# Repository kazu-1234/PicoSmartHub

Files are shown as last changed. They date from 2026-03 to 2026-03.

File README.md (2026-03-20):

# PicoSmartHub

PicoSmartHubは、Raspberry Pi Pico W 2（およびPico W）をコアとして開発された、多機能かつ統合的なスマートホームハブ兼環境測定ステーションです。
単なるセンサーノードにとどまらず、外部クラウドサービス（SwitchBot, LINE, Google Apps Script）との連携、赤外線通信、およびローカルネットワーク内での子機連携を安定して処理できるように設計されています。

## 外観・ハードウェア構成

メイン画面
メイン画面

### 電源供給について
本システムは、設置環境に応じて「USB給電」と「乾電池」の2種類の電源方式で動作するように設計されています。これにより、コンセントがない場所でもスタンドアローンで稼働させることが可能です。
**USBケーブルによる給電と、乾電池による給電を絶対に同時に行わないでください。**

## コア機能と技術詳細

本システムは、日常生活の利便性向上と環境監視を目的として、以下の主要な機能を備えています。

### 1. 高度な環境センシングと異常検知
本体および外部センサーを用いて、生活環境を常に監視します。
- **高精度な温湿度測定**: 本体内蔵のDHT20で室内の温湿度を常時測定します。また、屋外や別室を測定するための外部センサー（DHT22）は、本体のイヤホンジャック端子を利用して接続する設計となっており、用途に合わせて容易に着脱が可能です。すべての測定結果はLCDに一覧表示されます。
- **雷雲接近のリアルタイム検知**: AS3935雷センサーモジュールを搭載。ハードウェア割り込み（IRQ）を用いてバックグラウンドで雷の発生を監視し、検知時には「雷までの推定距離」を即座に算出して画面に警告表示します。同時にRGB LEDを黄色点滅させ、視覚的にも危険を知らせます。

### 2. 子機（PicoSmartHub_Sub）とのローカルネットワーク連携
同一Wi-Fiネットワーク内に配置した別プロジェクトの子機（[PicoSmartHub_Sub](https://github.com/kazu-1234/PicoSmartHub_Sub)）とTCP/IP経由で直接通信を行い、リアルタイムな状態共有を実現しています。
- **お風呂の湯張り監視システム**: 子機に搭載された超音波距離センサーが浴槽の水位を監視します。水位が事前に設定した閾値に達すると、子機から親機に対してプッシュ通知（HTTPリクエスト等）が送信されます。
- **親機側のアラート処理**: 通知を受け取った親機は、現在実行中の画面表示を強制的にオーバーライドして「お風呂が沸いたこと」を画面に大きく表示し、同時にRGB LEDを白色の無限点滅モードに切り替えてユーザーに確実に知らせます。

### 3. 統合的な家電制御（SwitchBot API & ローカル赤外線）
赤外線方式の家電を本機から一括制御します。
- **SwitchBotクラウド連携**: `config.h` に登録したSwitchBotのAPIトークンおよびデバイスIDを利用し、ネットワーク経由で照明、テレビ、エアコンなどを本体の物理ボタン・メニューから直接操作可能です。APIのレスポンス処理もマイコン内で完結しています。
- **赤外線（IR）の学習と送信**: 赤外線受信モジュールを用いて既存のリモコンの信号を読み取り、マイコン内に記録する学習モードを実装。記録した信号は赤外線送信LEDから出力でき、ローカル環境のみで完結する遅延のない家電操作を実現しています。

### 4. 双方向の外部サービス連携（GAS & LINE API）
マイコン単体では難しいデータの蓄積や遠隔からの操作を、Google Apps Script (GAS) とLINE Messaging APIを組み合わせることで解決しています。
- **環境データのクラウドロギング**: 定期的に温湿度データや雷の検知ログをGASへ送信し、Googleスプレッドシートに自動追記します。これにより、過去の環境データのグラフ化や分析が可能です。
LINEからの操作

- **LINEへの自動警告と遠隔操作**: 雷接近時にLINEへ自動でメッセージをプッシュ送信します。また、外出先からLINEのBot宛てに特定のメッセージ（例：「PC起動」）を送信すると、GASを経由して親機がそのリクエストを検知し、後述のWoL機能などを実行する双方向通信を構築しています。

### 5. Wake on LAN (WoL) によるPC電源管理
あらかじめ設定ファイルに登録されたデスクトップPCやホームサーバーのMACアドレスに対し、マジックパケットを生成・ブロードキャスト送信します。これにより、物理的なスイッチを押すことなく、本機からのメニュー操作やLINE経由でのリモート起動が可能です。

LINEからの操作

### 6. デュアルコアを活用したシステムアーキテクチャ
Raspberry Pi Pico W 2 のRP2350（またはRP2040）のデュアルコアを最大限に活用し、処理のブロッキングを防いでいます。
- **Core 0**: センサーの読み取り、LCDの描画、ボタン入力の判定、赤外線の送受信など、タイミングがシビアなハードウェア制御とUI処理を担当。
- **Core 1**: Wi-Fiの接続維持、HTTPリクエストの送信（SwitchBot/GAS等）、WoLパケットの生成、子機からの通信待受など、時間のかかる重いネットワーク処理をバックグラウンドで担当。

## 回路構成・ピンアサイン詳細

Raspberry Pi Pico W 2 (Pico W 互換) との結線は以下の通りです。

- **LCDディスプレイ (20x4文字表示 / LiquidCrystal互換)**
  - RS: GP2
  - E: GP3
  - D4: GP4, D5: GP5, D6: GP6, D7: GP7
  - バックライト (PWM調光用): GP14
- **RGB LED (ステータス・アラート用)**
  - Red: GP28, Green: GP27, Blue: GP26
- **ユーザーインターフェース**
  - 操作ボタン入力: GP15 (内部プルアップ有効)
- **I2Cバス (各種センサー通信用)**
  - SDA: GP0
  - SCL: GP1
  - 接続デバイス: DHT20 (室内温湿度), AS3935 (雷センサー)
- **センサー個別ピン**
  - AS3935 割り込み (IRQ): GP16
  - DHT22 (屋外用温湿度) データ: GP17 （※イヤホンジャック経由で着脱可能）
- **赤外線 (IR) モジュール**
  - IR受信 (OUT): GP18
  - IR送信LED (IN): GP19

## 導入・セットアップ手順

1. **開発環境の準備**
   Arduino IDEを使用します。ボードマネージャで Raspberry Pi Pico / RP2040 (earlephilhower版) をインストールしてください。
2. **必須ライブラリのインストール**
   ライブラリマネージャから以下のライブラリをインストールします。
   - `LiquidCrystal`
   - `DFRobot_DHT20`
   - `DHT sensor library` (Adafruit)
   - `SparkFun AS3935 Lightning Sensor`
   - `ArduinoJson`
   - `IRremote`
3. **`config.h` の設定**
   プロジェクト内の `config.h` を環境に合わせて編集してください。
   - Wi-Fi接続情報（複数APのフォールバック対応）
   - 固定IP・ゲートウェイ設定
   - 子機（PicoSmartHub_Sub）のIPアドレス
   - WoL対象機器のMACアドレス
   - 各種APIキー（SwitchBot, LINE, GASデプロイURL）
4. **コンパイルと書き込み**
   ボードを「Raspberry Pi Pico W」等に設定し、書き込みを行います。初回起動時はWi-Fi接続とNTPサーバーによる時刻同期が行われ、完了後にメインシステムが立ち上がります。

## ライセンス
本ソフトウェアは MIT License のもとで公開されています。詳細は `LICENSE` ファイルをご確認ください。

## 免責事項
本システムは個人開発によるプロジェクトです。本ソフトウェアおよびハードウェア設計の使用によって生じたいかなる損害（データの損失、家電の誤作動、感電等の事故）について、開発者は一切の責任を負いません。特に、子機を用いた水回りでの運用、WoL等による外部からのシステム起動、およびUSBと乾電池の電源取り扱いに関しては、十分な安全確認と自己責任の上で運用してください。

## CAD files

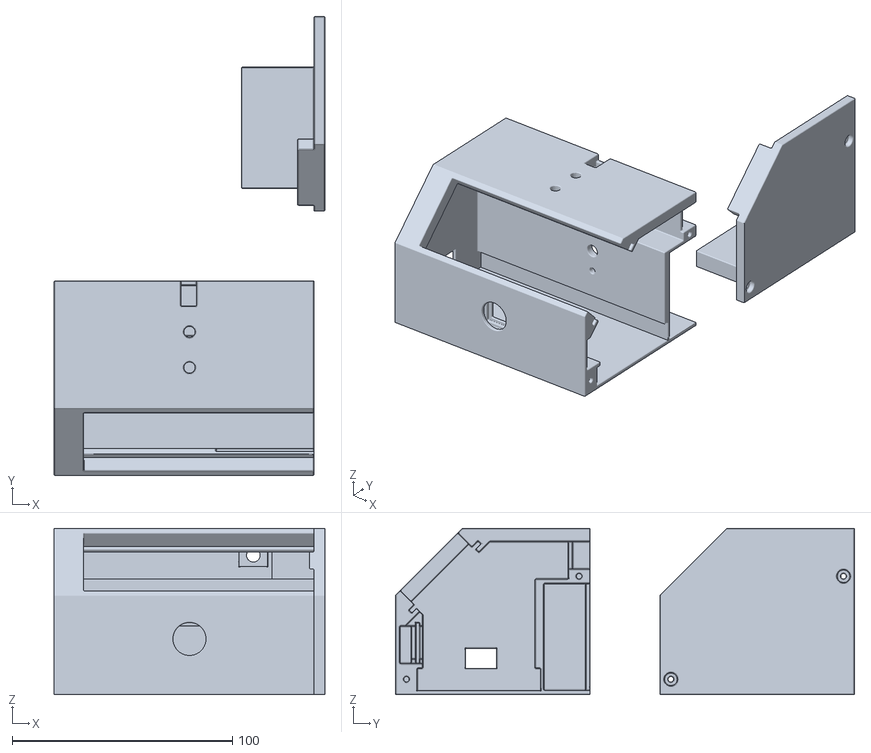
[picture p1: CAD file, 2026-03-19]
3D_data/PicoSmartHub.stl
123.0 x 208.4 x 75.5

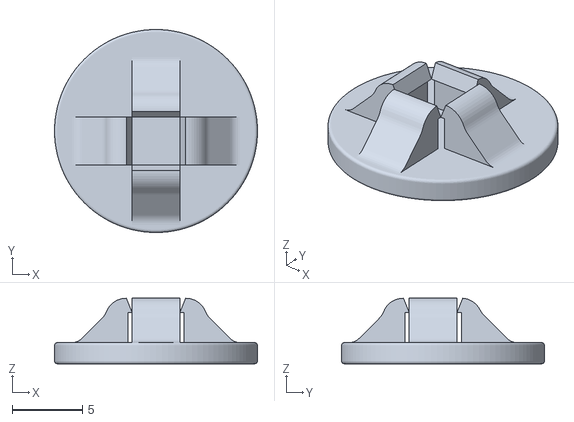
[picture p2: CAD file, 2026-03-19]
3D_data/PicoSmartHub_button.stl
14.4 x 14.4 x 4.65

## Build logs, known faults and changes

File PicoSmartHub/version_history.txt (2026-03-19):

Thunder Sensor - バージョン履歴
================================

v19.2.0
- 旧バージョン（安定版）

v19.3.0 (2026-03-06)
- 動作安定化修正（機能変更なし）
- HTTPリクエスト読み取りのbusy-waitにdelay(1)を追加してCPU解放・Watchdog保護
- handleLEDBlink()のmutex取得前にledBlinkActiveフラグの事前チェックを追加（mutex競合軽減）
- distance_start / distance_stop 送信後のdelay(100)→delay(10)に短縮
- requestSendBathClear処理のdelay(50)→delay(10)に短縮
- bath_clear処理のフォーマットバグ修正（{ の直後にコードが続いていた）
- SwitchBotコマンドキューのローカルバッファをゼロ初期化してNULL終端を保証

v19.3.1 (2026-03-06)
- 5-7秒間隔のフリーズ修正
- handleWolPollingのポーリング間隔を5秒→30秒に延長（Core1のwifi_mutex長時間保持を軽減）
- handleWolPollingのHTTPSリトライを除去し1回のみに変更、タイムアウトを5秒→3秒に短縮
- handleWolPolling内のdelay(200)→delay(100)に短縮
- logDataToGoogleSheetのタイムアウトを5秒→3秒に短縮
- handleActionFlags内のWiFiClient接続にsetTimeout(1000)を追加（接続タイムアウト1秒制限）
- handleActionFlags内のdelay()をflush()+stop()に置換（ノンブロッキング化）

v19.4.0 (2026-03-06)
- 起動直後の即フリーズおよびWatchdog再起動ループの原因（Core0 setup完了直前の String 型への代入時のヒープ競合）を修正（data_mutexによる保護を追加）
- 未確定なタイムアウト短縮やポーリング延長設定を破棄し、完全に安定動作していた旧バージョン（v19.2.0以前）の通信間隔・タイムアウト等に完全復元
  - GAS / WoLポーリング間隔を30秒→5秒に復元
  - GAS / WoL通信タイムアウトを3秒→5秒に復元
  - WoLポーリング通信のリトライ（2回）とdelay待機を復元

v19.6.0 (2026-03-07)
- 起動時フリーズおよび秒更新の定期停止の根本原因を修正（WiFiミューテックス長期保持・ブロッキングNTP）
- handleConnection(): NTP同期をステートマシン化し完全非同期化
  - 旧: for(i<60){ delay(200); } = 12秒間Core1完全ブロック → 起動直後にアニメーションが動かない原因
  - 新: NTP.begin()後すぐリターン、ntpWaiting/ntpWaitStartフラグで次ループにて結果確認
  - 12秒タイムアウトもノンブロッキングでmillis()比較により管理
- handleServerClient(): server.accept()前の不要なwifi_mutexロックを除去
  - server.accept()はブロッキングでなくポーリング操作のため排他不要
- handleWolPolling(): wifi_mutexを関数全体ではなくHTTPリクエストごとに取得・解放
  - 旧: 関数先頭でmutex取得→全HTTPリクエスト完了まで保持（最大25秒以上）→ 秒更新が定期停止する原因
  - 新: シグナル確認・コマンド取得・ACK送信の各リクエストを個別にmutex取得・解放
- handleWolPolling(): リトライ待機をdelay(500)→delay(100)に短縮

v19.5.0 (2026-03-06)
- 3〜30秒間隔の不規則フリーズ（Watchdog誤発火）の根本原因を修正
- petWatchdog()ヘルパーを追加し、loop()内の複数箇所から呼び出し
  - Display::update()のmutex待ち前後、handlePeriodicTasks()後、delay(10)直前も呼び出し
  - DHT22読み取り前後でも呼び出し（最大2.5秒かかる場合に対応）
- FREEZE_TIMEOUT_MSを10秒→15秒に延長（WiFi/HTTPS処理中の誤Watchdog防止）
- Display::update()のmutex_enter_blockingをtry_enterスピンに変更（デッドロック根絶）
  - Core1がwifi_mutex＋data_mutexを長時間保持中でもCore0がタイムアウトしない
  - 2秒以内にmutex取得できない場合はそのフレームのLCD更新をスキップ（次フレームで回復）
- checkInactivity()をtry_enter（取れなければスキップ）に変更
- handleLEDBlink()をtry_enter（取れなければその呼び出しをスキップ）に変更
- handleButton()の短押し・長押し処理をtry_enterスピンに変更
- loop()末尾の二重バックライトチェック（mutex_enter_blocking）を削除（handlePeriodicTasksで管理済み）
- Core1のloop1()でCore0起動完了前はWatchdog監視を開始しないよう変更（起動時誤トリガー防止）
- WiFi連続失敗時のdelay(5000)を1秒×5回ループに分割（Core1ループ停滞軽減）

v19.7.0 (2026-03-10)
- バグ修正: アプリから/api/ir/sendで送信されたIRコマンドが、Core0のloop()で一切処理されていなかった致命的バグを修正
  - Core1がHTTPリクエストからirSendRequestedフラグをセットしていたが、Core0にそのフラグを読み取るコードが存在しなかった
  - Core0のloop()末尾にフル対応のIRコマンドディスパッチ処理を追加
  - 対応デバイス: LIGHT(7コマンド), TV(40+コマンド), AIRCON(16コマンド), FAN(5コマンド), SPEAKER(22コマンド)
  - mutex保護下でフラグとコマンドデータを安全にコピーしてから信号送信を実行

v19.6.1 (2026-03-15)
- 温湿度センサー（DHT20）の初回読み取り成功時のみ、RGB LEDを青色で3回点滅する処理を追加
- 初回点滅は1回のみ実行されるよう、firstSensorReadBlinkDoneフラグで再実行を防止

v19.6.2 (2026-03-15)
- 仕様変更: LED点滅トリガーを「温湿度の初回読み取り成功時」から「IP経由 /api/sensors の初回JSON読み取り成功時」に変更
- /api/sensors のHTTP 200レスポンス送信成功後のみ、1回だけ青色3回点滅を実行
- firstJsonReadBlinkDoneフラグを追加し、2回目以降のJSONアクセスでは点滅しないように制御

v19.6.3 (2026-03-15)
- 仕様変更: LED点滅トリガーを「/api/sensors 初回成功時」から「ルートURL (/) の初回アクセス成功時」に変更
- ブラウザで http://<PicoのIP>/ へ最初にアクセスした1回目で、青色3回点滅するよう修正
- 互換性維持のため /api/sensors 初回アクセスでも同じ1回点滅判定を共有

[v19.8.0] - 2026-03-15
  - IR送信時の文字列比較失敗バグを修正 (device/cmd変数の未初期化とstrncpyの終端処理を修正)

[v19.8.1] - 2026-03-15
  - 起動時のLED点灯終了とバックライト消灯・メイン画面遷移のタイミングを同期化 (LED点灯中に初期化処理を行うよう順序を修正)

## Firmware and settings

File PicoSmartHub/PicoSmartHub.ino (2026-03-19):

#include <Arduino.h>

//================================================================
// ライブラリ
//================================================================
#include <WiFi.h>
#include <WiFiServer.h>
#include <WiFiClientSecure.h>
#include <HTTPClient.h>
#include <Wire.h>
#include <LiquidCrystal.h>
#include <time.h>
#include <stdlib.h>
#include <WiFiNTP.h>
#include <DFRobot_DHT20.h>
#include <DHT.h>           // DHT22屋外温度センサー用
#include <SparkFun_AS3935.h>
#include <ArduinoJson.h>
#include <WiFiUdp.h>
#include <LittleFS.h>
#include <math.h> // for round()
#include <ArduinoOTA.h>
#include <pico/mutex.h>
#include "hardware/watchdog.h" // Watchdog機能のために追加

// ★設定ファイルを読み込む
#include "config.h"
#undef DEBUG_PRINT
#undef DEBUG_PRINTLN
#define SUPPRESS_SEND_PWM_BY_TIMER_INFO
#define NO_LED_FEEDBACK_CODE
#define SEND_PWM_BY_TIMER
#include <IRremote.hpp>
#include "my_remotes.h"

// ★Mutexの定義
auto_init_mutex(data_mutex); // 共有データ保護用
auto_init_mutex(wifi_mutex); // Wi-Fiアクセス保護用

// ★Watchdogとフリーズ検出関連
#define CRASH_MAGIC_VALUE 0xDEADBEEF
const unsigned long FREEZE_TIMEOUT_MS = 15000; // v19.5.0: 10秒→15秒に延長（WiFi/HTTP処理中の誤検出防止）
volatile unsigned long lastCore0Pet = 0;

// ★ Watchdog pet のインラインヘルパー (Core0がmutex待ち中でも安全に呼べる)
static inline void petWatchdog() { lastCore0Pet = millis(); }

// ★コア間通信用の変数
volatile bool core0_hw_init_complete = false;
volatile bool core1_wifi_complete = false;
volatile int wolTriggerAction = 0; // 0:なし, 1:Desktop, 2:Server

// ★Core0からCore1へのアクションリクエスト用フラグ
volatile bool requestManualLog = false;
volatile bool requestGetSwitchbotIds = false;
volatile bool requestSendLineTest = false;
volatile bool requestResyncNtp = false;
volatile bool requestSendLightningAlert = false;
volatile int lightningDistanceForAlert = 0;
volatile bool requestSendWolDesktop = false;
volatile bool requestSendWolServer = false;
volatile bool requestGetUltrasonicDistance = false;
volatile bool requestSendDistanceStop = false;    // Core0→Core1: 子機に/distance_stopを送信
volatile bool requestSendDistanceStart = false;   // Core0→Core1: 子機に/distance_startを送信
volatile bool requestExitUltrasonic = false;      // Core1→Core0: ULTRASONIC_MONITORを終了導指

// IR APIリモコン送信用 (Core1がセット → Core0が処理)
volatile char irSendDevice[32] = "";
volatile char irSendCommand[32] = "";
volatile bool irSendRequested = false;

// SwitchBotコマンドキュー: Core0からのリクエストをCore1が実行
struct SwitchBotPendingCmd {
    char deviceId[64];
    char command[32];
    char parameter[64];
    char commandType[16];
    bool pending;
} pendingSwitchBotCmd = {"", "", "", "command", false};

volatile bool requestSendBathClear = false; // Core0→Core1: 子機に /bath_clear を送信

// ★Core1からCore0への情報共有用バッファ
volatile char sharedIpAddress[16] = "Connecting...";

//================================================================
// ★★★ 設定項目 (本体の動作設定) ★★★
//================================================================
// --- 雷センサー感度設定 ---
const uint8_t LIGHTNING_WATCHDOG_THRESHOLD = 1; // 雷検知の強さの閾値 (調整範囲: 1～10)
const uint8_t LIGHTNING_SPIKE_REJECTION = 1;    // 電気的ノイズの除去レベル (調整範囲: 1～11)
const uint8_t INITIAL_NOISE_LEVEL = 1;          // 周囲の環境ノイズの初期レベル (調整範囲: 1～7)

// --- 動作設定 ---
const unsigned long LONG_PRESS_DURATION_MS = 1000;
const unsigned long INACTIVITY_TIMEOUT_MS = 5000;
const unsigned long BACKLIGHT_DURATION_MS = 3000;
const unsigned long BACKLIGHT_FADE_MS = 100;        // v19.0.0: バックライトのフェード時間（0.1秒）
const unsigned long SENSOR_READ_INTERVAL_MS = 3000; // 温湿度センサーの読み取り間隔
const unsigned long IP_DISPLAY_DURATION_MS = 5000;
const int HISTORY_SIZE = 3;
const int LCD_COLS = 20;
const int LCD_ROWS = 4;

//================================================================
// ピン定義
//================================================================
namespace Pins
{
    const int LCD_RS = 2, LCD_E = 3, LCD_D4 = 4, LCD_D5 = 5, LCD_D6 = 6, LCD_D7 = 7;
    const int LCD_BACKLIGHT = 14;
    const int LED_R = 28, LED_G = 27, LED_B = 26;
    const int BUTTON = 15;
    const int I2C_SDA = 0, I2C_SCL = 1;
    const int LIGHTNING_IRQ = 16;
    const int DHT22_PIN = 17;  // DHT22屋外温度センサー
    const int AS3935_ADDR = 0x03;
    const int IR_RECEIVE_PIN = 18;
    const int IR_SEND_PIN = 19;
}

//================================================================
// グローバル状態管理
//================================================================
namespace State
{
    // --- 動作モード ---
    enum Mode
    {
        MAIN_DISPLAY,
        MENU,
        HISTORY,
        SWITCHBOT_APPLIANCE_SELECT,
        DEVICE_CONTROL,
        WAKE_ON_LAN,
        ULTRASONIC_MONITOR,
        SENSOR_DIAGNOSTICS,
        IR_APPLIANCE_SELECT,
        IR_DEVICE_CONTROL,
        IR_RECEIVE_MODE
    };

    // --- メニューの状態 ---
    struct MenuState
    {
        Mode currentMode = MAIN_DISPLAY;
        int menuSelection = 0;
        int deviceSelection = 0;
        int commandSelection = 0;
    };

    // --- システムの状態 ---
    struct SystemState
    {
        bool illuminationOn = false;
        bool backlightAlwaysOn = false;
        bool ntpInitialized = false;
        bool isAutoResync = false;
        bool needsRedraw = true;
        bool forceMainScreenRedraw = true;
        uint8_t currentNoiseLevel = 2;
        bool initialLogSent = false;
        bool dht20_initialized = false;
        bool dht22_outdoor_initialized = false;  // DHT22屋外センサー初期化フラグ
        bool firstHttpAccessBlinkDone = false;   // 初回HTTPアクセス時LED点滅済みフラグ
        bool as3935_initialized = false;
        int displayMode = 0;
        bool displayModeManuallySet = false;

        // v19.0.0: バックライトPWM制御用
        bool backlightFading = false;
        bool backlightTargetOn = false;
        unsigned long backlightFadeStartTime = 0;
        int backlightCurrentBrightness = 0;
        
        bool forceClockRefresh = false;
        bool debugModeRuntime = DEBUG; // 初期値はconfig.hのDEBUGに従う
        int irLearningApplianceIndex = -1;
        int irLearningButtonIndex = -1;
        bool irLearningComplete = false;
        bool irLearningWaitingSerial = true;
        bool bathAlertActive = false;    // お風呂通知アクティブフラグ
    };

    // --- センサーデータ ---
    struct SensorData
    {
        float temperature = -999.0;
        float humidity = -999.0;
        float outdoorTemperature = -999.0;  // DHT22屋外温度
        float outdoorHumidity = -999.0;     // DHT22屋外湿度
        float ultrasonicDistance = -1.0;
        char lastEventTime[20] = "N/A";
        String lastEventType = "None"; // "Lightning" or "Noise"
        int lastLightningDistance = -1;
    };

    // --- 本体メモリに記録する雷履歴 ---
    struct EventRecord
    {
        char timestamp[20];
        String type;
        int distance;
    };

    struct HistoryState
    {
        EventRecord records[HISTORY_SIZE];
        int index = 0;
        int count = 0;
    };

    // --- タイマー ---
    struct TimerState
    {
        unsigned long lastActivity = 0;
        unsigned long backlightOn = 0;
        // フルスクリーンメッセージ用
        char timedMessageLine0[LCD_COLS + 1] = "";
        char timedMessageLine1[LCD_COLS + 1] = "";
        unsigned long timedMessageEndTime = 0;
        bool returnToMainAfterMessage = false;
        bool messageNeedsRedraw = false; // メッセージの再描画要求フラグ
        // 2行目上書きメッセージ用
        char timedOverlayLine1[LCD_COLS + 1] = "";
        unsigned long timedOverlayEndTime = 0;
        
        // LED点滅用 (ノンブロッキング)
        bool ledBlinkActive = false;
        unsigned long ledBlinkNextToggle = 0;
        int ledBlinkRemainingToggles = 0;
        int ledBlinkInterval = 0;
        String ledBlinkColor = "";
        bool ledCurrentState = false;
        bool ledBlinkInfinite = false;   // trueなら無限点滅 (お風呂通知用)
        unsigned long lastDistanceUpdateTime = 0; // 子機からの距離プッシュ最終受信時刻
    };

    // --- 暗号化コンテキスト ---
    struct SHA256_CTX
    {
        uint8_t data[64];
        uint32_t datalen;
        uint64_t bitlen;
        uint32_t state[8];
    };

    // --- グローバルオブジェクトと状態変数のインスタンス ---
    MenuState menu;
    SystemState system;
    SensorData sensors;
    HistoryState history;
    TimerState timers;

    LiquidCrystal lcd(Pins::LCD_RS, Pins::LCD_E, Pins::LCD_D4, Pins::LCD_D5, Pins::LCD_D6, Pins::LCD_D7);
    DFRobot_DHT20 dht20;
    SparkFun_AS3935 lightning(Pins::AS3935_ADDR);
    WiFiServer server(80);
    String childIpAddress = "";
    volatile bool lightningInterruptFlag = false;
}

// DHT22屋外温度センサー（グローバルオブジェクト）
DHT g_dht22(Pins::DHT22_PIN, DHT22);
const float DHT22_TEMP_OFFSET = 0.0;   // 温度キャリブレーションオフセット
const float DHT22_HUM_OFFSET = -15.0;  // 湿度キャリブレーションオフセット

// DHT22の安定化設定
const unsigned long DHT22_MIN_READ_INTERVAL_MS = 2500; // DHT22の最小読み取り間隔（2.5秒に設定）
const int DHT22_MAX_RETRY = 0;  // 読み取りリトライ回数（Core0ブロック防止のため0に設定）
const unsigned long DHT22_RETRY_DELAY_MS = 100; // リトライ間の待機時間
static unsigned long lastDHT22ReadTime = 0; // 前回の読み取り時刻
static float lastValidTemp = -999.0;  // 前回の有効な温度値
static float lastValidHum = -999.0;   // 前回の有効な湿度値
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
void loop()
{
    petWatchdog(); // Watchdogをリセット（最優先）

    // ★ デバッグ情報の定期的なシリアル出力
    if (DEBUG)
    {
        static unsigned long lastDebugPrint = 0;
        if (millis() - lastDebugPrint > 2000)
        { // 2秒ごとに出力
            lastDebugPrint = millis();
            mutex_enter_blocking(&data_mutex);
            float temp = State::sensors.temperature;
            float hum = State::sensors.humidity;
            String eventType = State::sensors.lastEventType;
            mutex_exit(&data_mutex);
            Serial.printf("[Core0 Sensor Status] Temp: %.1f C, Humidity: %.1f %%, Last Event: %s\n", temp, hum, eventType.c_str());
        }
    }

    // ★ 起動後の初回ログ
    bool ntpReady;
    bool initialLogDone;
    mutex_enter_blocking(&data_mutex);
    ntpReady = State::system.ntpInitialized;
    initialLogDone = State::system.initialLogSent;
    mutex_exit(&data_mutex);

    if (ntpReady && !initialLogDone)
    {
        requestManualLog = true;
        mutex_enter_blocking(&data_mutex);
        State::system.initialLogSent = true;
        mutex_exit(&data_mutex);
        if (DEBUG)
            Serial.println("[Core0] Triggering initial spreadsheet log.");
    }

    // --- 常時実行するタスク ---
    Input::handleButton(); // ボタン入力は常に監視
    Sensors::update();     // 雷割り込みフラグは常にチェック
    IRRemote::handle();    // IR受信チェック

    // v19.0.0: バックライトのPWMフェード更新（フェード中のみ高頻度実行）
    if (State::system.backlightFading)
    {
        Utils::updateBacklightFade();
    }

    petWatchdog(); // Display::update()のmutex待ち後にもリセット
    Display::update();       // 画面表示は常に更新
    petWatchdog(); // 表示処理後にもリセット
    Menu::checkInactivity(); // 無操作タイムアウトを監視

    // --- 周期的に実行するタスク (2秒サイクル) ---
    handlePeriodicTasks();
    petWatchdog(); // 周期タスク後にもリセット

    // ★ Core1からのWoLトリガーを処理 (非同期)
    if (wolTriggerAction > 0)
    {
        int triggerType = wolTriggerAction;
        wolTriggerAction = 0; // フラグをクリア

        if (DEBUG)
            Serial.printf("[Core0] Received WoL trigger: Type %d\n", triggerType);

        const char *targetName = (triggerType == 1) ? "Desktop PC" : "Server PC";

        // ★ LCDの2行目にメッセージを上書き表示 (タイマー式)
        // v19.5.0: try_enterでデッドロック回避
        if (mutex_try_enter(&data_mutex, nullptr)) {
            snprintf(State::timers.timedOverlayLine1, LCD_COLS + 1, "WoL Sent: %s", targetName);
            State::timers.timedOverlayEndTime = millis() + 2000;
            State::system.forceMainScreenRedraw = true; // メイン画面を再描画してオーバーレイを表示
            mutex_exit(&data_mutex);
        }

        // ★ WoLパケット送信とLED点滅をCore1に依頼
        if (triggerType == 1)
        {
            requestSendWolDesktop = true;
        }
        else
        {
            requestSendWolServer = true;
        }
    }

    if (State::system.illuminationOn)
    {
        Utils::handleSmoothIllumination();
    }

    // Core1からのULTRASONIC_MONITOR終了指示を処理 (子機が自ら終了したとき)
    if (requestExitUltrasonic)
    {
        requestExitUltrasonic = false;
        requestGetUltrasonicDistance = false; // 残留ポーリングも同時キャンセル
        // v19.5.0: try_enterでデッドロック回避
        if (mutex_try_enter(&data_mutex, nullptr)) {
            if (State::menu.currentMode == State::ULTRASONIC_MONITOR) {
                Menu::changeMode(State::MAIN_DISPLAY);
            }
            mutex_exit(&data_mutex);
        }
    }

    // ★ Core1からのAPI経由IR送信リクエストを処理
    if (irSendRequested)
    {
        // フラグとコマンドデータを安全にコピー
        char device[32] = {0};
        char cmd[32] = {0};
        mutex_enter_blocking(&data_mutex);
        strncpy(device, (const char*)irSendDevice, sizeof(device));
        strncpy(cmd, (const char*)irSendCommand, sizeof(cmd));
        irSendRequested = false;
        mutex_exit(&data_mutex);

        if (DEBUG)
            Serial.printf("[Core0] IR API dispatch: device=%s, cmd=%s\n",
                device, cmd);

        // デバイス名とコマンド名から信号を検索して送信
        const IrSignal* signal = nullptr;
        String dev(device);
        String c(cmd);

        if (dev == "LIGHT")
        {
            if      (c == "POWER")      signal = &signal_LIGHT_POWER;
            else if (c == "BRIGHT_UP")  signal = &signal_LIGHT_BRIGHT_UP;
            else if (c == "BRIGHT_DOWN") signal = &signal_LIGHT_BRIGHT_DOWN;
            else if (c == "COLOR_COOL") signal = &signal_LIGHT_COLOR_COOL;
            else if (c == "COLOR_WARM") signal = &signal_LIGHT_COLOR_WARM;
            else if (c == "SLEEP_TIMER") signal = &signal_LIGHT_SLEEP_TIMER;
            else if (c == "FULL_LIGHT") signal = &signal_LIGHT_FULL_LIGHT;
        }
        else if (dev == "TV")
        {
            if      (c == "POWER")       signal = &signal_TV_POWER;
            else if (c == "INPUT")       signal = &signal_TV_INPUT;
            else if (c == "VOL_UP")      signal = &signal_TV_VOL_UP;
            else if (c == "VOL_DOWN")    signal = &signal_TV_VOL_DOWN;
            else if (c == "CH_UP")       signal = &signal_TV_CH_UP;
            else if (c == "CH_DOWN")     signal = &signal_TV_CH_DOWN;
            else if (c == "MUTE")        signal = &signal_TV_MUTE;
            else if (c == "TERRESTRIAL") signal = &signal_TV_TERRESTRIAL;
            else if (c == "BS_CS")       signal = &signal_TV_BS_CS;
            else if (c == "UP")          signal = &signal_TV_UP;
            else if (c == "DOWN")        signal = &signal_TV_DOWN;
            else if (c == "LEFT")        signal = &signal_TV_LEFT;
            else if (c == "RIGHT")       signal = &signal_TV_RIGHT;
            else if (c == "OK")          signal = &signal_TV_OK;
            else if (c == "MENU")        signal = &signal_TV_MENU;
            else if (c == "HOME")        signal = &signal_TV_HOME;
            else if (c == "RETURN")      signal = &signal_TV_RETURN;
            else if (c == "GUIDE")       signal = &signal_TV_GUIDE;
            else if (c == "DDATA")       signal = &signal_TV_DDATA;
            else if (c == "SUBMENU")     signal = &signal_TV_SUBMENU;
            else if (c == "REC_LIST")    signal = &signal_TV_REC_LIST;
            else if (c == "DISPLAY")     signal = &signal_TV_DISPLAY;
            else if (c == "CC")          signal = &signal_TV_CC;
            else if (c == "AUDIO")       signal = &signal_TV_AUDIO;
            else if (c == "BLUE")        signal = &signal_TV_BLUE;
            else if (c == "RED")         signal = &signal_TV_RED;
            else if (c == "GREEN")       signal = &signal_TV_GREEN;
            else if (c == "YELLOW")      signal = &signal_TV_YELLOW;
            else if (c == "REWIND")      signal = &signal_TV_REWIND;
            else if (c == "PLAY")        signal = &signal_TV_PLAY;
            else if (c == "PAUSE")       signal = &signal_TV_PAUSE;
            else if (c == "FFWD")        signal = &signal_TV_FFWD;
            else if (c == "PREV")        signal = &signal_TV_PREV;
            else if (c == "REC")         signal = &signal_TV_REC;
            else if (c == "STOP")        signal = &signal_TV_STOP;
            else if (c == "NEXT")        signal = &signal_TV_NEXT;
            else if (c == "3DIGIT")      signal = &signal_TV_3DIGIT;
            else if (c == "NETFLIX")     signal = &signal_TV_NETFLIX;
            else if (c == "HULU")        signal = &signal_TV_HULU;
            else if (c == "UNEXT")       signal = &signal_TV_UNEXT;
            else if (c == "ABEMATV")     signal = &signal_TV_ABEMATV;
            else if (c == "YOUTUBE")     signal = &signal_TV_YOUTUBE;
            else if (c == "TVER")        signal = &signal_TV_TVER;
            // 数字チャンネル
            else if (c == "1")           signal = &signal_TV_1;
            else if (c == "2")           signal = &signal_TV_2;
            else if (c == "3")           signal = &signal_TV_3;
            else if (c == "4")           signal = &signal_TV_4;
            else if (c == "5")           signal = &signal_TV_5;
            else if (c == "6")           signal = &signal_TV_6;
            else if (c == "7")           signal = &signal_TV_7;
            else if (c == "8")           signal = &signal_TV_8;
            else if (c == "9")           signal = &signal_TV_9;
            else if (c == "10")          signal = &signal_TV_10;
            else if (c == "11")          signal = &signal_TV_11;
            else if (c == "12")          signal = &signal_TV_12;
        }
        else if (dev == "AIRCON")
        {
            if      (c == "POWER")          signal = &signal_AIRCON_POWER;
            else if (c == "COOL_ON")        signal = &signal_AIRCON_COOL_ON;
            else if (c == "HEAT_ON")        signal = &signal_AIRCON_HEAT_ON;
            else if (c == "OFF")            signal = &signal_AIRCON_OFF;
            else if (c == "TEMP_UP")        signal = &signal_AIRCON_TEMP_UP;
            else if (c == "TEMP_DOWN")      signal = &signal_AIRCON_TEMP_DOWN;
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

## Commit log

2026-03-19 Organize Raspberry Pi Arduino files into their own folder
2026-03-19 Adjust image width for LINE操作 in README
    Updated image size for LINE操作 section in README.
